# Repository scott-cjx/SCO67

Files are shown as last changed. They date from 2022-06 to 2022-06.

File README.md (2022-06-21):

# SCO67

## For action
### Hardware
Main: <br>
- SW61 is not connected -> Solder jumper from D50 to D61
- D41 & D65 (COL 14) not connected (not accounted for) -> Solder new connection to carrier board.
- Capslock (SW29) is out of place.

Daughter Board: <br>
- Connections on WEACT PI PICO RP2040 is incorrectly reflected to headers in kicad

### Software
- microcontroller does not start immediately on boot. 
    - reviewed and solved temporarly by mounting device in boot.py
- Found limitation that there is max 6kro (6 Key Roll Over) not NKRO!!

Layers are not implemented fully
Multikey actions are not implemented fully

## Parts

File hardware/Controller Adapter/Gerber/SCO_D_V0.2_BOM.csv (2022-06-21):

Id | Designator | Package | Quantity | Designation | Supplier and ref
1 | J1,J2 | PinHeader_1x20_P2.54mm_Vertical | 2 | Conn_01x20
2 | SCOD1 | Daughter Rev 0.2 | 1 | Daughter Rev 0.2

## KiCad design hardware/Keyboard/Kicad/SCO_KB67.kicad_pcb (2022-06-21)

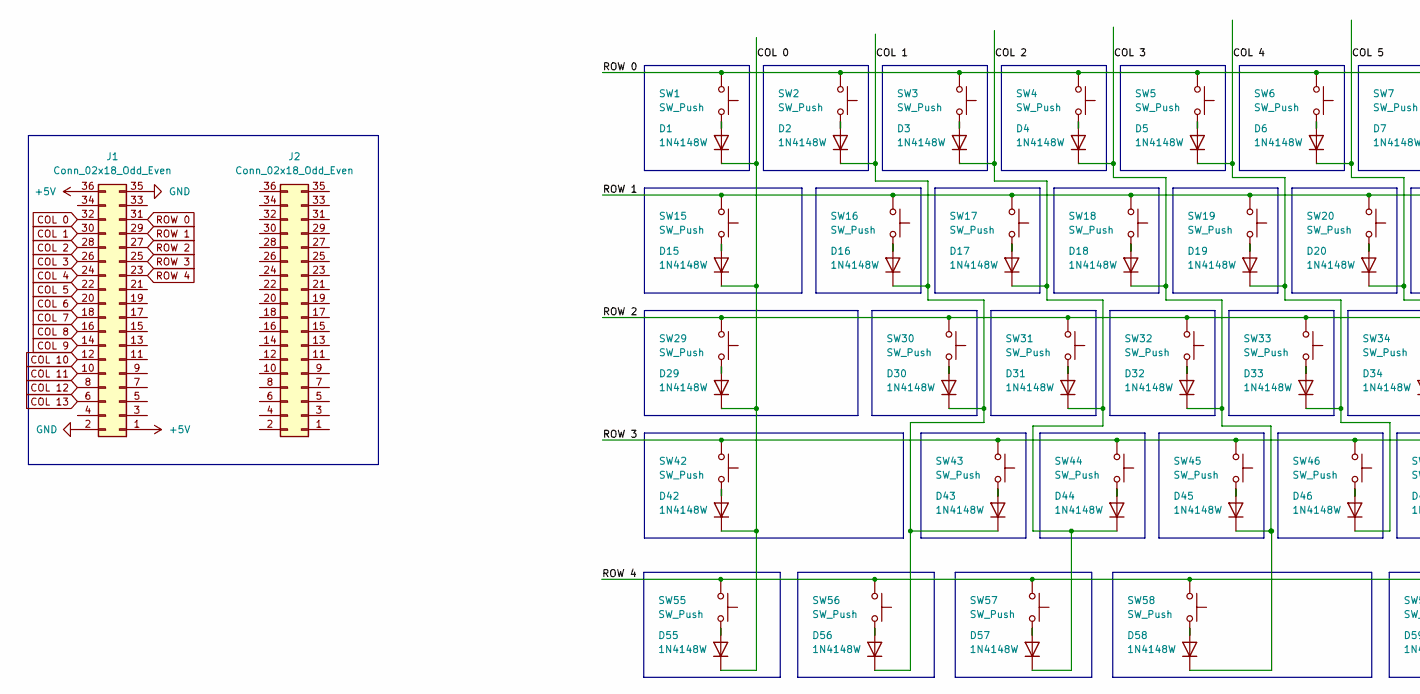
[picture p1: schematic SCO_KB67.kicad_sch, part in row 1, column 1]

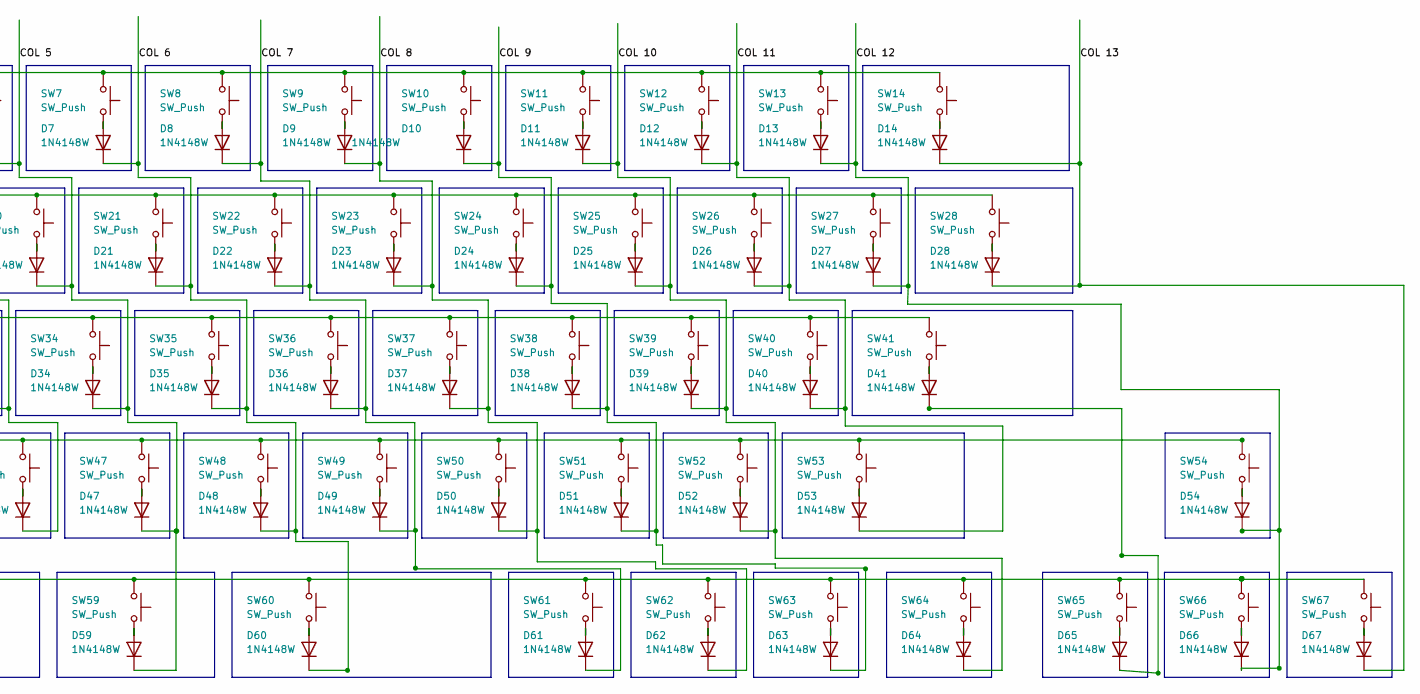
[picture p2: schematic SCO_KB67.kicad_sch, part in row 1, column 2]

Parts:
D1, D2, D3, D4, D5, D6, D7, D8, D9, D10, D11, D12, D13, D14, D15, D16, D17, D18, D19, D20, D21, D22, D23, D24, D25, D26, D27, D28, D29, D30, D31, D32, D33, D34, D35, D36, D37, D38, D39, D40, D41, D42, D43, D44, D45, D46, D47, D48, D49, D50, D51, D52, D53, D54, D55, D56, D57, D58, D59, D60, D61, D62, D63, D64, D65, D66, D67: 1N4148W; D_SOD-123
J1, J2: Conn_02x18_Odd_Even; PinHeader_2x18_P2.54mm_Vertical
SW1, SW2, SW3, SW4, SW5, SW6, SW7, SW8, SW9, SW10, SW11, SW12, SW13, SW14, SW15, SW16, SW17, SW18, SW19, SW20, SW21, SW22, SW23, SW24, SW25, SW26, SW27, SW28, SW29, SW30, SW31, SW32, SW33, SW34, SW35, SW36, SW37, SW38, SW39, SW40, SW41, SW42, SW43, SW44, SW45, SW46, SW47, SW48, SW49, SW50, SW51, SW52, SW53, SW54, SW55, SW56, SW57, SW58, SW59, SW60, SW61, SW62, SW63, SW64, SW65, SW66, SW67: SW_Push; SW_MX

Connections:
COL 0: D1.1 (K), D15.1 (K), D29.1 (K), D42.1 (K), D55.1 (K); also elsewhere on the board
COL 1: D2.1 (K), D16.1 (K), D30.1 (K), D43.1 (K), D56.1 (K); also elsewhere on the board
COL 2: D3.1 (K), D17.1 (K), D31.1 (K), D44.1 (K), D57.1 (K); also elsewhere on the board
COL 3: D4.1 (K), D18.1 (K), D32.1 (K), D45.1 (K), D58.1 (K); also elsewhere on the board
COL 4: D5.1 (K), D19.1 (K), D33.1 (K), D46.1 (K); also elsewhere on the board
COL 5: D6.1 (K), D20.1 (K), D34.1 (K), D47.1 (K), D59.1 (K); also elsewhere on the board
COL 6: D7.1 (K), D21.1 (K), D35.1 (K), D48.1 (K), D60.1 (K); also elsewhere on the board
COL 7: D8.1 (K), D22.1 (K), D36.1 (K), D49.1 (K); also elsewhere on the board
COL 8: D9.1 (K), D23.1 (K), D37.1 (K), D50.1 (K), D62.1 (K); also elsewhere on the board
COL 9: D10.1 (K), D24.1 (K), D38.1 (K), D51.1 (K), D63.1 (K); also elsewhere on the board
COL 10: D11.1 (K), D25.1 (K), D39.1 (K), D52.1 (K), D64.1 (K); also elsewhere on the board
COL 11: D12.1 (K), D26.1 (K), D40.1 (K), D53.1 (K); also elsewhere on the board
COL 12: D13.1 (K), D27.1 (K), D54.1 (K), D66.1 (K); also elsewhere on the board
COL 13: D14.1 (K), D28.1 (K), D67.1 (K); also elsewhere on the board
unnamed: D1.2 (A), SW1.2
unnamed: D2.2 (A), SW2.2
unnamed: D3.2 (A), SW3.2
unnamed: D4.2 (A), SW4.2
unnamed: D5.2 (A), SW5.2
unnamed: D6.2 (A), SW6.2
unnamed: D7.2 (A), SW7.2
unnamed: D8.2 (A), SW8.2
unnamed: D9.2 (A), SW9.2
unnamed: D10.2 (A), SW10.2
unnamed: D11.2 (A), SW11.2
unnamed: D12.2 (A), SW12.2
unnamed: D13.2 (A), SW13.2
unnamed: D14.2 (A), SW14.2
unnamed: D15.2 (A), SW15.2
unnamed: D16.2 (A), SW16.2
unnamed: D17.2 (A), SW17.2
unnamed: D18.2 (A), SW18.2
unnamed: D19.2 (A), SW19.2
unnamed: D20.2 (A), SW20.2
unnamed: D21.2 (A), SW21.2
unnamed: D22.2 (A), SW22.2
unnamed: D23.2 (A), SW23.2
unnamed: D24.2 (A), SW24.2
unnamed: D25.2 (A), SW25.2
unnamed: D26.2 (A), SW26.2
unnamed: D27.2 (A), SW27.2
unnamed: D28.2 (A), SW28.2
unnamed: D29.2 (A), SW29.2
unnamed: D30.2 (A), SW30.2
unnamed: D31.2 (A), SW31.2
unnamed: D32.2 (A), SW32.2
unnamed: D33.2 (A), SW33.2
unnamed: D34.2 (A), SW34.2
unnamed: D35.2 (A), SW35.2
unnamed: D36.2 (A), SW36.2
unnamed: D37.2 (A), SW37.2
unnamed: D38.2 (A), SW38.2
unnamed: D39.2 (A), SW39.2
unnamed: D40.2 (A), SW40.2
unnamed: D41.2 (A), SW41.2
unnamed: D42.2 (A), SW42.2
unnamed: D43.2 (A), SW43.2
unnamed: D44.2 (A), SW44.2
unnamed: D45.2 (A), SW45.2
unnamed: D46.2 (A), SW46.2
unnamed: D47.2 (A), SW47.2
unnamed: D48.2 (A), SW48.2
unnamed: D49.2 (A), SW49.2
unnamed: D50.2 (A), SW50.2
unnamed: D51.2 (A), SW51.2
unnamed: D52.2 (A), SW52.2
unnamed: D53.2 (A), SW53.2
unnamed: D54.2 (A), SW54.2
unnamed: D55.2 (A), SW55.2
unnamed: D56.2 (A), SW56.2
unnamed: D57.2 (A), SW57.2
unnamed: D58.2 (A), SW58.2
unnamed: D59.2 (A), SW59.2
unnamed: D60.2 (A), SW60.2
unnamed: D61.2 (A), SW61.2
unnamed: D62.2 (A), SW62.2
unnamed: D63.2 (A), SW63.2
unnamed: D64.2 (A), SW64.2
unnamed: D41.1 (K), D65.1 (K)
unnamed: D65.2 (A), SW65.2
unnamed: D66.2 (A), SW66.2
unnamed: D67.2 (A), SW67.2
unnamed: J1.1, J1.36
unnamed: J1.2, J1.35
ROW 0: SW1.1, SW2.1, SW3.1, SW4.1, SW5.1, SW6.1, SW7.1, SW8.1, SW9.1, SW10.1, SW11.1, SW12.1, SW13.1, SW14.1; also elsewhere on the board
ROW 1: SW15.1, SW16.1, SW17.1, SW18.1, SW19.1, SW20.1, SW21.1, SW22.1, SW23.1, SW24.1, SW25.1, SW26.1, SW27.1, SW28.1; also elsewhere on the board
ROW 2: SW29.1, SW30.1, SW31.1, SW32.1, SW33.1, SW34.1, SW35.1, SW36.1, SW37.1, SW38.1, SW39.1, SW40.1, SW41.1; also elsewhere on the board
ROW 3: SW42.1, SW43.1, SW44.1, SW45.1, SW46.1, SW47.1, SW48.1, SW49.1, SW50.1, SW51.1, SW52.1, SW53.1, SW54.1; also elsewhere on the board
ROW 4: SW55.1, SW56.1, SW57.1, SW58.1, SW59.1, SW60.1, SW61.1, SW62.1, SW63.1, SW64.1, SW65.1, SW66.1, SW67.1; also elsewhere on the board

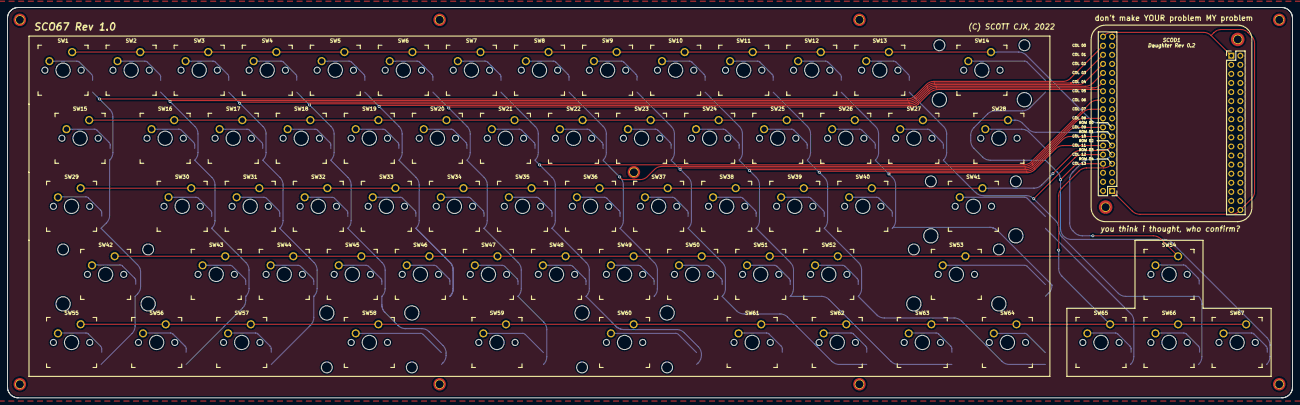
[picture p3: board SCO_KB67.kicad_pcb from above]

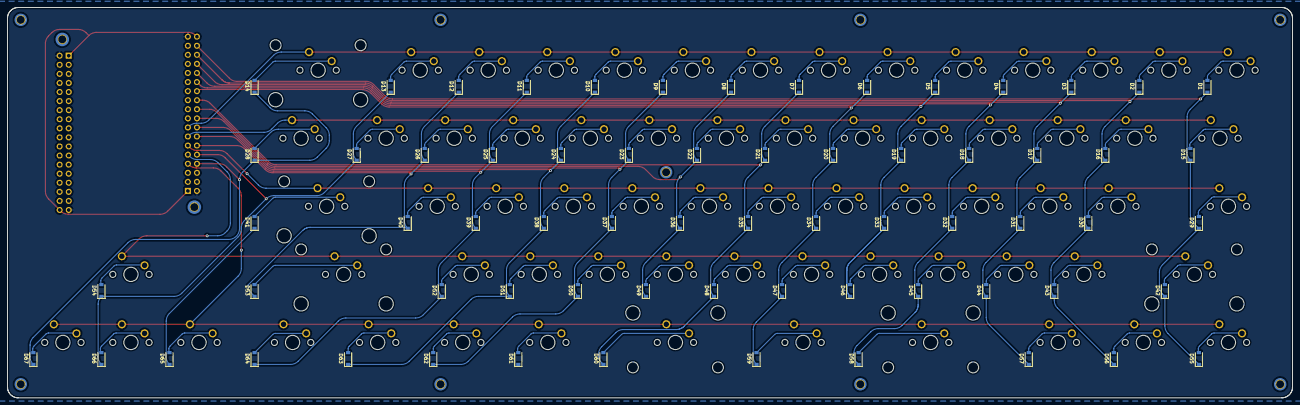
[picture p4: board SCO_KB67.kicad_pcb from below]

Board: 2 copper layers, 359.7 x 109.3 mm, 150 parts (67 on the bottom side), 89 nets.

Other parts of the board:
MH1, MH2, MH3, MH4, MH5, MH6, MH7, MH8, MH9: MountingHole_2.2mm_M2_ISO7380_Pad_TopBottom
SCOD1: Daughter Rev 0.2
STAB1, STAB2, STAB3, STAB4, STAB5, STAB6: Stabilizer_MX_2u

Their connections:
+5V: SCOD1.1, SCOD1.36
COL 0: SCOD1.34; also elsewhere on the board
COL 1: SCOD1.32; also elsewhere on the board
COL 2: SCOD1.30; also elsewhere on the board
COL 3: SCOD1.28; also elsewhere on the board
COL 4: SCOD1.26; also elsewhere on the board
COL 5: SCOD1.24; also elsewhere on the board
COL 6: SCOD1.22; also elsewhere on the board
COL 7: SCOD1.20; also elsewhere on the board
COL 8: SCOD1.18; also elsewhere on the board
COL 9: SCOD1.16; also elsewhere on the board
COL 10: SCOD1.14; also elsewhere on the board
COL 11: SCOD1.12; also elsewhere on the board
COL 12: SCOD1.10; also elsewhere on the board
COL 13: SCOD1.8; also elsewhere on the board
GND: SCOD1.2, SCOD1.35
ROW 0: SCOD1.15; also elsewhere on the board
ROW 1: SCOD1.13; also elsewhere on the board
ROW 2: SCOD1.11; also elsewhere on the board
ROW 3: SCOD1.9; also elsewhere on the board
ROW 4: SCOD1.7; also elsewhere on the board

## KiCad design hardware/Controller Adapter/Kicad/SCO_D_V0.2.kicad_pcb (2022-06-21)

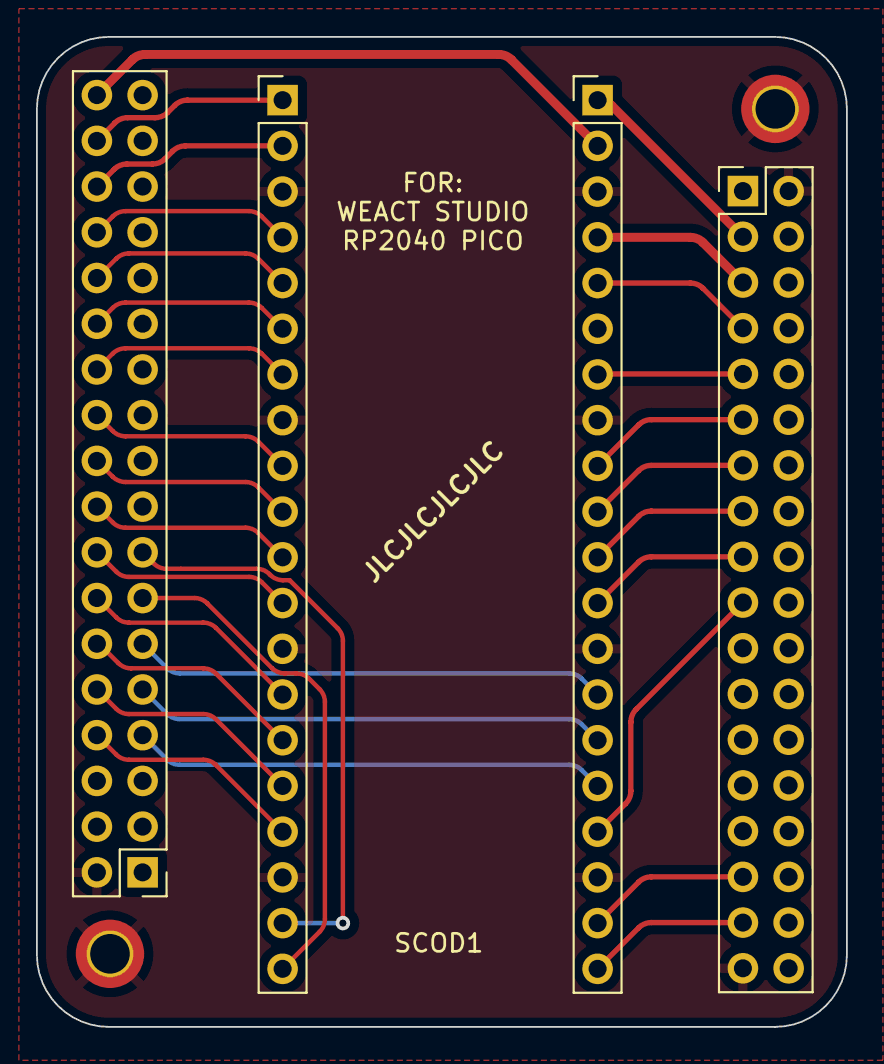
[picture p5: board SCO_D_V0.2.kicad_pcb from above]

Board: 2 copper layers, 45.0 x 55.0 mm, 3 parts (0 on the bottom side), 32 nets.

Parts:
J1, J2: Conn_01x20; PinHeader_1x20_P2.54mm_Vertical
SCOD1: Daughter Rev 0.2

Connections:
+3V3: J2.4, SCOD1.5
GND: J1.3, J1.8, J1.13, J1.18, J2.3, J2.8, J2.13, J2.18, SCOD1.1, SCOD1.2, SCOD1.35
IO 0: J1.1, SCOD1.34
IO 1: J1.2, SCOD1.32
IO 2: J1.4, SCOD1.30
IO 3: J1.5, SCOD1.28
IO 4: J1.6, SCOD1.26
IO 5: J1.7, SCOD1.24
IO 6: J1.9, SCOD1.22
IO 7: J1.10, SCOD1.20
IO 8: J1.11, SCOD1.18
IO 9: J1.12, SCOD1.16
IO 10: J1.14, SCOD1.14
IO 11: J1.15, SCOD1.12
IO 12: J1.16, SCOD1.10
IO 13: J1.17, SCOD1.8
IO 14: J1.19, SCOD1.15
IO 15: J1.20, SCOD1.13
IO 16: J2.14, SCOD1.11
IO 17: J2.15, SCOD1.9
IO 18: J2.16, SCOD1.7
IO 19: J2.17, SCOD1.19
IO 20: J2.5, SCOD1.7
IO 21: J2.7, SCOD1.9
IO 22: J2.9, SCOD1.11
IO 23: J2.12, SCOD1.17
SCL 0: J2.10, SCOD1.13
SDA 0: J2.11, SCOD1.15
UART0 RX: J2.19, SCOD1.31
UART0 TX: J2.20, SCOD1.33
VBUS: J2.1, SCOD1.3
VCC: J2.2, SCOD1.36

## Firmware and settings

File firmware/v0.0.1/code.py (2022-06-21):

import SCO67_DEF

import keyboard_vio
import keyboard_phyio
from keynames import KEYNAMES

import usb_hid
import time

from adafruit_hid.keyboard import Keyboard
from adafruit_hid.keyboard_layout_us import KeyboardLayoutUS

LOOP_INTERVAL = 0.5
PHY_DEF = SCO67_DEF.SCO67_PHY_DEF

keyboard = Keyboard(usb_hid.devices)
keyboard_layout = KeyboardLayoutUS(keyboard)

kbd_io: keyboard_phyio.KeyboardPhyIO
kbd_vio: keyboard_vio.KeyboardVirtualIO
kbd_status: keyboard_phyio.KeyboardStatus
kbd_layers: keyboard_vio.KeyboardLayers
kbd_action: keyboard_vio.KeyboardAction

kbd_io = keyboard_phyio.KeyboardPhyIO(PHY_DEF)
kbd_io.setup()
kbd_status = keyboard_phyio.KeyboardStatus(kbd_io)
kbd_vio = keyboard_vio.KeyboardVirtualIO(kbd_io, kbd_status)

kbd_layers = keyboard_vio.KeyboardLayers()
kbd_layers.load("/keymap/base_keymap.txt")
kbd_layers.load("/keymap/layer2_keymap.txt")
kbd_layers.switch_layer_to("base")

kbd_action = keyboard_vio.KeyboardAction(kbd_layers, kbd_status, keyboard)

while 1:
    update = kbd_status.scan_diff()
    # kbd_status.print_if_update()
    if kbd_status.get_if_update():
        kbd_action.act_on_report()

    # time.sleep(LOOP_INTERVAL)

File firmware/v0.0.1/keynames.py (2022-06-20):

KEYNAMES = {
	'A': 0x04, # Keyboard a and A
	'B': 0x05, # Keyboard b and B
	'C': 0x06, # Keyboard c and C
	'D': 0x07, # Keyboard d and D
	'E': 0x08, # Keyboard e and E
	'F': 0x09, # Keyboard f and F
	'G': 0x0a, # Keyboard g and G
	'H': 0x0b, # Keyboard h and H
	'I': 0x0c, # Keyboard i and I
	'J': 0x0d, # Keyboard j and J
	'K': 0x0e, # Keyboard k and K
	'L': 0x0f, # Keyboard l and L
	'M': 0x10, # Keyboard m and M
	'N': 0x11, # Keyboard n and N
	'O': 0x12, # Keyboard o and O
	'P': 0x13, # Keyboard p and P
	'Q': 0x14, # Keyboard q and Q
	'R': 0x15, # Keyboard r and R
	'S': 0x16, # Keyboard s and S
	'T': 0x17, # Keyboard t and T
	'U': 0x18, # Keyboard u and U
	'V': 0x19, # Keyboard v and V
	'W': 0x1a, # Keyboard w and W
	'X': 0x1b, # Keyboard x and X
	'Y': 0x1c, # Keyboard y and Y
	'Z': 0x1d, # Keyboard z and Z

	'1': 0x1e, # Keyboard 1 and !
	'2': 0x1f, # Keyboard 2 and @
	'3': 0x20, # Keyboard 3 and #
	'4': 0x21, # Keyboard 4 and $
	'5': 0x22, # Keyboard 5 and %
	'6': 0x23, # Keyboard 6 and ^
	'7': 0x24, # Keyboard 7 and &
	'8': 0x25, # Keyboard 8 and *
	'9': 0x26, # Keyboard 9 and (
	'0': 0x27, # Keyboard 0 and )

	'ENTER': 0x28, # Keyboard Return (ENTER)
	'ESC': 0x29, # Keyboard ESCAPE
	'ESCAPE': 0x29, # Keyboard ESCAPE
	'BACKSPACE': 0x2a, # Keyboard DELETE (Backspace)
	'TAB': 0x2b, # Keyboard Tab
	'SPACE': 0x2c, # Keyboard Spacebar
	'LEFTBRACE': 0x2f, # Keyboard [ and {
	'LEFTBRACKET': 0x2f, # Keyboard [ and {
	'MINUS': 0x2d, # Keyboard - and _
	'EQUAL': 0x2e, # Keyboard = and +
	'EQUALS': 0x2e, # Keyboard = and +
	'PLUS': 0x2e, # Keyboard = and +
	'RIGHTBRACE': 0x30, # Keyboard ] and }
	'RIGHTBRACKET': 0x30, # Keyboard ] and }
	'BACKSLASH': 0x31, # Keyboard \ and |
	'HASHTILDE': 0x32, # Keyboard Non-US # and ~
	'HASHANDTILDE': 0x32, # Keyboard Non-US # and ~
	'SEMICOLON': 0x33, # Keyboard ; and :
	'APOSTROPHE': 0x34, # Keyboard ' and "
	'QUOTE': 0x34, # Keyboard ' and "
	'GRAVE': 0x35, # Keyboard ` and ~
	'BACKTICK': 0x35, # Keyboard ` and ~
	'TILDE': 0x35, # Keyboard ` and ~
	'COMMA': 0x36, # Keyboard , and <
	'DOT': 0x37, # Keyboard . and >
	'PERIOD': 0x37, # Keyboard . and >
	'SLASH': 0x38, # Keyboard / and ?
	'FORWARDSLASH': 0x38, # Keyboard / and ?
	'CAPSLOCK': 0x39, # Keyboard Caps Lock

	'F1': 0x3a, # Keyboard F1
	'F2': 0x3b, # Keyboard F2
	'F3': 0x3c, # Keyboard F3
	'F4': 0x3d, # Keyboard F4
	'F5': 0x3e, # Keyboard F5
	'F6': 0x3f, # Keyboard F6
	'F7': 0x40, # Keyboard F7
	'F8': 0x41, # Keyboard F8
	'F9': 0x42, # Keyboard F9
	'F10': 0x43, # Keyboard F10
	'F11': 0x44, # Keyboard F11
	'F12': 0x45, # Keyboard F12

	'SYSRQ': 0x46, # Keyboard Print Screen
	'SCROLLLOCK': 0x47, # Keyboard Scroll Lock
	'PAUSE': 0x48, # Keyboard Pause
	'INSERT': 0x49, # Keyboard Insert
	'HOME': 0x4a, # Keyboard Home
	'PAGEUP': 0x4b, # Keyboard Page Up
	'DELETE': 0x4c, # Keyboard Delete Forward
	'END': 0x4d, # Keyboard End
	'PAGEDOWN': 0x4e, # Keyboard Page Down
	'RIGHT': 0x4f, # Keyboard Right Arrow
	'RIGHTARROW': 0x4f, # Keyboard Right Arrow
	'LEFT': 0x50, # Keyboard Left Arrow
	'LEFTARROW': 0x50, # Keyboard Left Arrow
	'DOWN': 0x51, # Keyboard Down Arrow
	'DOWNARROW': 0x51, # Keyboard Down Arrow
	'UP': 0x52, # Keyboard Up Arrow
	'UPARROW': 0x52, # Keyboard Up Arrow

	'NUMLOCK': 0x53, # Keyboard Num Lock and Clear
	'KPSLASH': 0x54, # Keypad /
	'NUMPADSLASH': 0x54, # Keypad /
	'KPASTERISK': 0x55, # Keypad *
	'NUMPADASTERISK': 0x55, # Keypad *
	'NUMPADTIMES': 0x55, # Keypad *
	'KPMINUS': 0x56, # Keypad -
	'NUMPADMINUS': 0x56, # Keypad -
	'KPPLUS': 0x57, # Keypad +
	'NUMPADPLUS': 0x57, # Keypad +
	'KPENTER': 0x58, # Keypad ENTER
	'NUMPADENTER': 0x58, # Keypad ENTER
	'KP1': 0x59, # Keypad 1 and End
	'NUMPAD1': 0x59, # Keypad 1 and End
	'KP2': 0x5a, # Keypad 2 and Down Arrow
	'NUMPAD2': 0x5a, # Keypad 2 and Down Arrow
	'KP3': 0x5b, # Keypad 3 and PageDn
	'NUMPAD3': 0x5b, # Keypad 3 and PageDn
	'KP4': 0x5c, # Keypad 4 and Left Arrow
	'NUMPAD4': 0x5c, # Keypad 4 and Left Arrow
	'KP5': 0x5d, # Keypad 5
	'NUMPAD5': 0x5d, # Keypad 5
	'KP6': 0x5e, # Keypad 6 and Right Arrow
	'NUMPAD6': 0x5e, # Keypad 6 and Right Arrow
	'KP7': 0x5f, # Keypad 7 and Home
	'NUMPAD7': 0x5f, # Keypad 7 and Home
	'KP8': 0x60, # Keypad 8 and Up Arrow
	'NUMPAD8': 0x60, # Keypad 8 and Up Arrow
	'KP9': 0x61, # Keypad 9 and Page Up
	'NUMPAD9': 0x61, # Keypad 9 and Page Up
	'KP0': 0x62, # Keypad 0 and Insert
	'NUMPAD0': 0x62, # Keypad 0 and Insert
	'KPDOT': 0x63, # Keypad . and Delete
	'NUMPADDOT': 0x63, # Keypad . and Delete

	'102ND': 0x64, # Keyboard Non-US \ and |
	'COMPOSE': 0x65, # Keyboard Application
	'POWER': 0x66, # Keyboard Power
	'KPEQUAL': 0x67, # Keypad =
	'NUMPADEQUAL': 0x67, # Keypad =
	'NUMPADEQUALS': 0x67, # Keypad =

	'F13': 0x68, # Keyboard F13
	'F14': 0x69, # Keyboard F14
	'F15': 0x6a, # Keyboard F15
	'F16': 0x6b, # Keyboard F16
	'F17': 0x6c, # Keyboard F17
	'F18': 0x6d, # Keyboard F18
	'F19': 0x6e, # Keyboard F19
	'F20': 0x6f, # Keyboard F20
	'F21': 0x70, # Keyboard F21
	'F22': 0x71, # Keyboard F22
	'F23': 0x72, # Keyboard F23
	'F24': 0x73, # Keyboard F24

	'OPEN': 0x74, # Keyboard Execute
	'HELP': 0x75, # Keyboard Help
	'PROPS': 0x76, # Keyboard Menu
	'FRONT': 0x77, # Keyboard Select
	'STOP': 0x78, # Keyboard Stop
	'AGAIN': 0x79, # Keyboard Again
	'UNDO': 0x7a, # Keyboard Undo
	'CUT': 0x7b, # Keyboard Cut
	'COPY': 0x7c, # Keyboard Copy
	'PASTE': 0x7d, # Keyboard Paste
	'FIND': 0x7e, # Keyboard Find
	'MUTE': 0x7f, # Keyboard Mute
	'VOLUMEUP': 0x80, # Keyboard Volume Up
	'VOLUMEDOWN': 0x81, # Keyboard Volume Down
	'KPCOMMA': 0x85, # Keypad Comma
	'KEYPAD EQUAL': 0x86,  # Keypad Equal Sign
	'RO': 0x87, # Keyboard International1
	'KATAKANAHIRAGANA': 0x88, # Keyboard International2
	'YEN': 0x89, # Keyboard International3
	'HENKAN': 0x8a, # Keyboard International4
	'MUHENKAN': 0x8b, # Keyboard International5
	'KPJPCOMMA': 0x8c, # Keyboard International6
	'HANGEUL': 0x90, # Keyboard LANG1
	'HANJA': 0x91, # Keyboard LANG2
	'KATAKANA': 0x92, # Keyboard LANG3
	'HIRAGANA': 0x93, # Keyboard LANG4
	'ZENKAKUHANKAKU': 0x94, # Keyboard LANG5
	'KPLEFTPAREN': 0xb6, # Keypad (
	'KPRIGHTPAREN': 0xb7, # Keypad )

	'CTRL': 0xe0, # Keyboard Left Control # Todo autodetect
	'CONTROL': 0xe0, # Keyboard Left Control
	'LEFTCTRL': 0xe0, # Keyboard Left Control
	'LEFTCONTROL': 0xe0, # Keyboard Left Control
	'SHIFT': 0xe1, # Keyboard Left Shift
	'LEFTSHIFT': 0xe1, # Keyboard Left Shift
	'ALT': 0xe2, # Keyboard Left Alt
	'LEFTALT': 0xe2, # Keyboard Left Alt
	'LEFTMETA': 0xe3, # Keyboard Left GUI
	'WINDOWS': 0xe3, # Keyboard Left GUI
	'GUI': 0xe3, # Keyboard Left GUI  # TODO auto detect side
	'LEFTGUI': 0xe3, # Keyboard Left GUI
	'LEFTWINDOWS': 0xe3, # Keyboard Left GUI
	'RIGHTCTRL': 0xe4, # Keyboard Right Control
	'RIGHTCONTROL': 0xe4, # Keyboard Right Control
	'RIGHTSHIFT': 0xe5, # Keyboard Right Shift
	'RIGHTALT': 0xe6, # Keyboard Right Alt
	'RIGHTMETA': 0xe7, # Keyboard Right GUI
	'RIGHTWINDOWS': 0xe7, # Keyboard Right GUI
	'RIGHTGUI': 0xe7, # Keyboard Right GUI
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
